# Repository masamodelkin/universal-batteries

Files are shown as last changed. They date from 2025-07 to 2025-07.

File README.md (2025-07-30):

# universal-batteries

Are you tired that all of those "wireless" devices actually require wires to charge them? Are you tired of all those wires on your table? Do you want to build a DIY project but you don't know what batteries to use? Or maybe you are not sure if wireless is the solution due to inconveniences with charging? 

If you answered yes to any of that, this project is for you! I personally answered yes to all of them, so I decided to make this modular battery system, so they can be swapped in seconds and no wires will be needed to charge any of the wireless tech that I have (not all of them, but most of them). 

This project introduces a simple design of a battery shell, charger and module that can be inserted into any project (or even existing electronics) to make it support hot-swap batteries and make all project batteries compatible with each other. 

The design features a charging station to charge 3 batteries at a time controlled with an ESP32-C6 allowing wireless control over it, battery shell design supporting 503759 batteries (1200mAh), and a battery bay to integrate into any project. 

This project is a work in progress, none of the electronics have been tested yet, including firmware and PCB. 

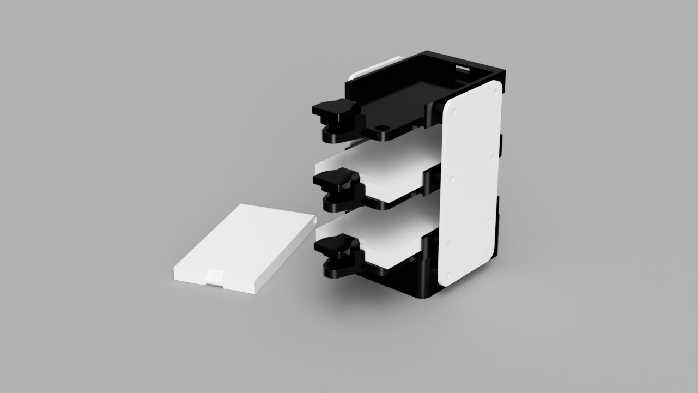
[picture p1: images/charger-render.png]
Charger render


Here is the routed PCB for the charger:

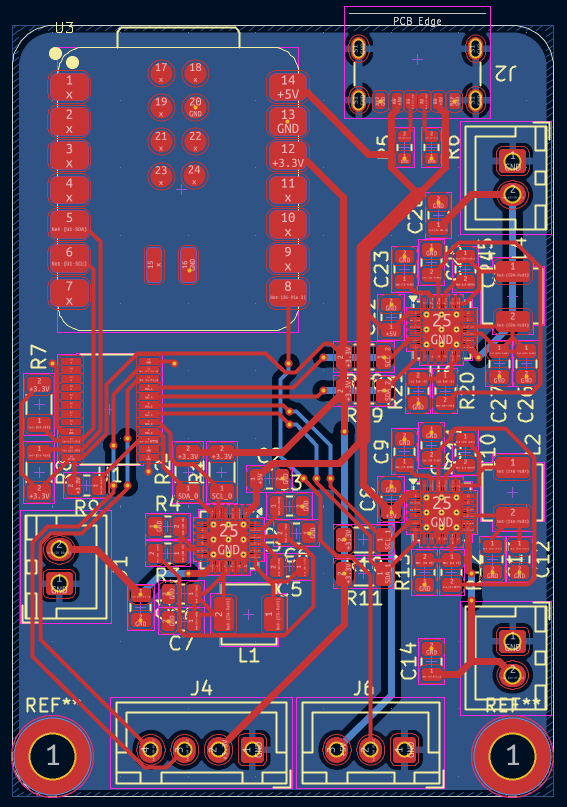
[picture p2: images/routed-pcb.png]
Complete routed PCB layout


## Bill of Materials (BOM)

| Component | Quantity | Unit Price | Total Price | Link |
|---|---|---|---|---|
| PCB (assembled) | 1 | 55.38 USD (35.38 + 20 shipping) | 55.38 USD | - |
| XIAO ESP32-C6 | 1 | 15.63 CAD (8.19 + 7.01 shipping + 0.43 antenna) | 15.63 CAD | [AliExpress](https://www.aliexpress.com/item/1005006935181127.html) |
| JST XH Connector Set (2-pin x3, 3-pin x1, 4-pin x1) | 1 | 6.92 CAD | 6.92 CAD | [AliExpress](https://www.aliexpress.com/item/1005009383841966.html) |
| Battery 503759 (1200mAh) | 3 | 14.94 CAD (pack of 3) | 14.94 CAD | [AliExpress](https://www.aliexpress.com/item/1005007102975858.html) |
| M3x6 Screws | 18 | - | - | - |
| M3x4x5 Heat Inserts | 18 | 7.55 CAD | 7.55 CAD | [AliExpress](https://www.aliexpress.com/item/1005009193787820.html) |
| Pogo Pins Connector 1x4 Male 4mm | 6 | 3.32 CAD | 19.92 CAD | [AliExpress](https://www.aliexpress.com/item/1005005380466642.html) |
| Pogo Pins Connector 1x4 Female 4mm | 6 | 3.48 CAD | 20.88 CAD | [AliExpress](https://www.aliexpress.com/item/1005005380466642.html) |
| Magnets 6x3mm | 18 | 11.24 CAD (4.33 + 6.91 shipping) | 11.24 CAD | [AliExpress](https://www.aliexpress.com/item/1005009258751295.html) |
| Magnets 6x2mm | 4 | 12.09 CAD (2.89 + 9.20 shipping) | 12.09 CAD | [AliExpress](https://www.aliexpress.com/item/1005009461555694.html) |
| PLA Filament | ~150g | Already own | 0.00 | - |
| **TOTAL** | | | **134.42 USD** | |

*Note: Prices include shipping where applicable. Some components may be sold in larger quantities than needed.*

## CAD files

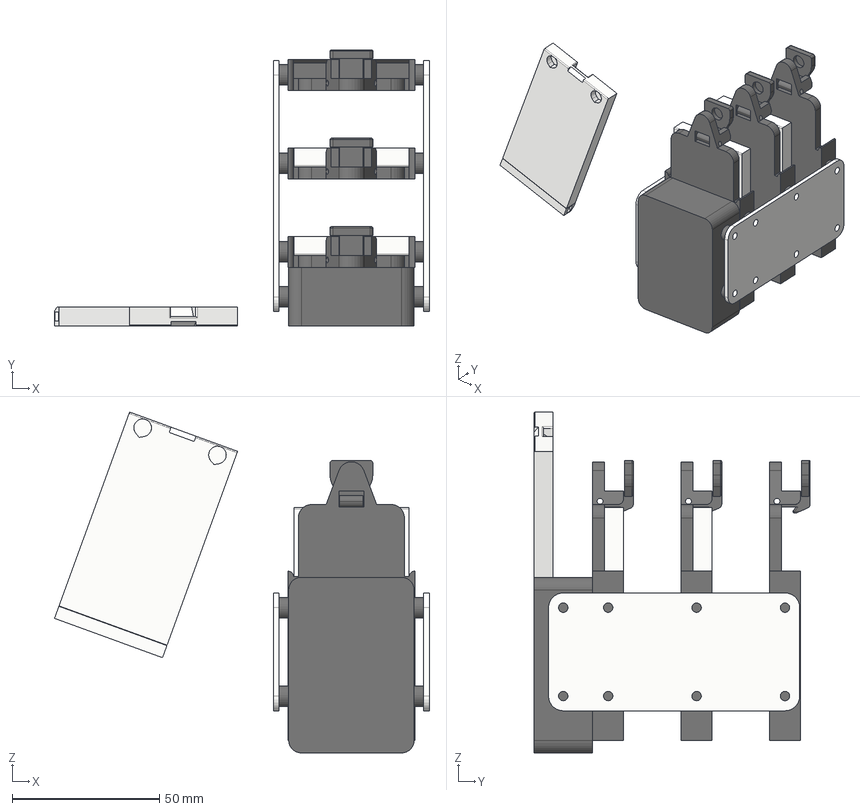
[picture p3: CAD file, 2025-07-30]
CAD/Removable batteries system.step
127.2 x 93.8 x 115.7 mm
Charger module x 3
Battery shell x 3
Battery cap x 3
Side panel x 2
JST_XH_B2B-XH-A_1x02_P2.50mm_Vertical x 3
C_0805_2012Metric x 21
R_1206_3216Metric x 8
R_0805_2012Metric x 7
TSSOP-24_4.4x7.8mm_P0.65mm
JST_XH_B4B-XH-A_1x04_P2.50mm_Vertical
Texas_RTW_WQFN-24-1EP_4x4mm_P0.5mm_EP2.7x2.7mm x 3
R_0603_1608Metric x 2
USB_C_Receptacle_GCT_USB4125-xx-x_6P_TopMnt_Horizontal
JST_XH_B3B-XH-A_1x03_P2.50mm_Vertical
1s_Battery_charger_PCB

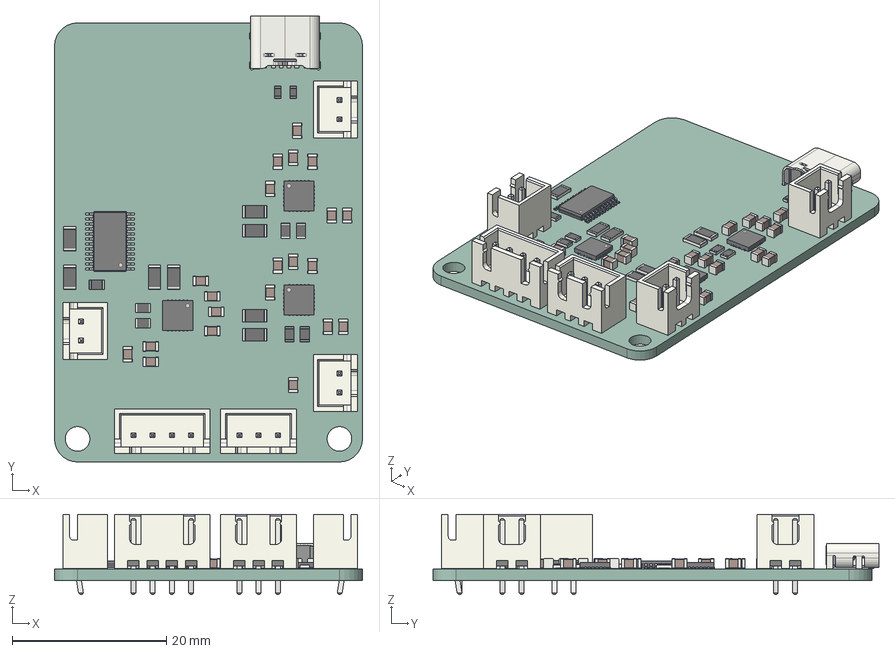
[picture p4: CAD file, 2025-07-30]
PCB/1s_Battery_charger.step
40.0 x 57.9 x 10.4 mm
JST_XH_B2B-XH-A_1x02_P2.50mm_Vertical x 3
C_0805_2012Metric x 21
R_1206_3216Metric x 8
R_0805_2012Metric x 7
TSSOP-24_4.4x7.8mm_P0.65mm
JST_XH_B4B-XH-A_1x04_P2.50mm_Vertical
Texas_RTW_WQFN-24-1EP_4x4mm_P0.5mm_EP2.7x2.7mm x 3
R_0603_1608Metric x 2
USB_C_Receptacle_GCT_USB4125-xx-x_6P_TopMnt_Horizontal
JST_XH_B3B-XH-A_1x03_P2.50mm_Vertical
1s_Battery_charger_PCB

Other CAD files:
CAD/Removable batteries system.f3z

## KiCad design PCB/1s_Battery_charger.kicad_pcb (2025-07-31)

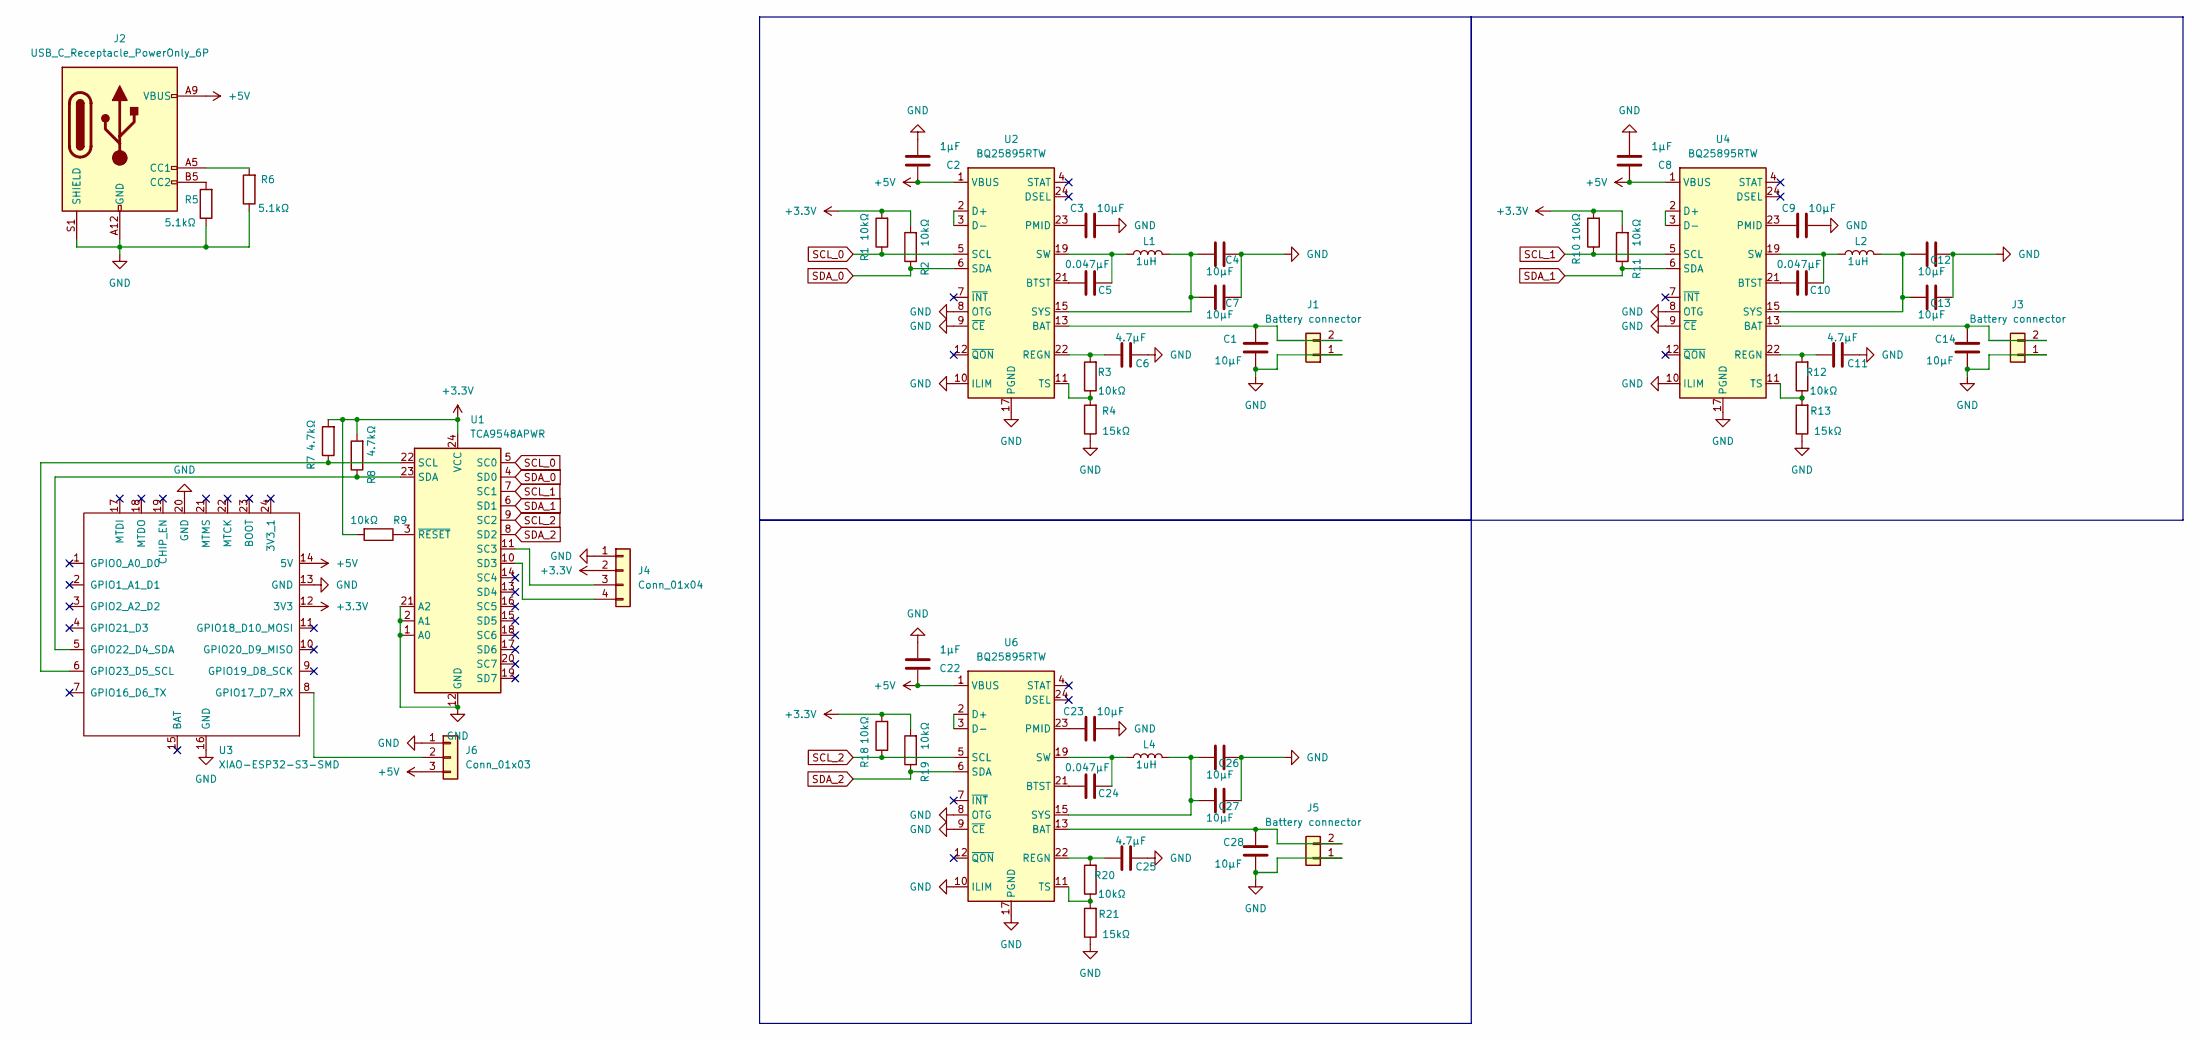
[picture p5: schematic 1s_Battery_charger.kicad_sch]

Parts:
C1, C14, C28: 10µF; C_0805_2012Metric
C2, C8, C22: 1μF; C_0805_2012Metric
C3, C4, C7, C9, C12, C13, C23, C26, C27: 10μF; C_0805_2012Metric
C5, C10, C24: 0.047μF; C_0805_2012Metric
C6, C11, C25: 4.7μF; C_0805_2012Metric
J1, J3, J5: Battery connector; JST_XH_B2B-XH-A_1x02_P2.50mm_Vertical
J2: USB_C_Receptacle_PowerOnly_6P; USB_C_Receptacle_GCT_USB4125-xx-x_6P_TopMnt_Horizontal
J4: Conn_01x04; JST_XH_B4B-XH-A_1x04_P2.50mm_Vertical
J6: Conn_01x03; JST_XH_B3B-XH-A_1x03_P2.50mm_Vertical
L1, L2, L4: 1uH; L_Changjiang_FXL0420
R1, R2, R10, R11, R18, R19: 10kΩ; R_1206_3216Metric
R3, R9, R12, R20: 10kΩ; R_0805_2012Metric
R4, R13, R21: 15kΩ; R_0805_2012Metric
R5, R6: 5.1kΩ; R_0603_1608Metric
R7, R8: 4.7kΩ; R_1206_3216Metric
U1: TCA9548APWR; TSSOP-24_4.4x7.8mm_P0.65mm
U2, U4, U6: BQ25895RTW; Texas_RTW_WQFN-24-1EP_4x4mm_P0.5mm_EP2.7x2.7mm_ThermalVias
U3: XIAO-ESP32-S3-SMD; XIAO-ESP32C6-SMD

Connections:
+3.3V: J4.2, R1.2, R2.2, R7.2, R8.2, R9.2, R10.2, R11.2, R18.2, R19.2, U1.24 (VCC), U3.12 (3V3)
+5V: C2.1, C8.1, C22.1, J2.A9 (VBUS), J2.B9 (VBUS), J6.3, U2.1 (VBUS), U3.14 (5V), U4.1 (VBUS), U6.1 (VBUS)
GND: C1.2, C2.2, C3.2, C4.2, C6.1, C7.2, C8.2, C9.2, C11.1, C12.2, C13.2, C14.2, C22.2, C23.2, C25.1, C26.2, C27.2, C28.2, J1.1, J2.A12 (GND), J2.B12 (GND), J2.S1 (SHIELD), J3.1, J4.1, J5.1, J6.1, R4.1, R5.1, R6.1, R13.1, R21.1, U1.1 (A0), U1.2 (A1), U1.12 (GND), U1.21 (A2), U2.8 (OTG), U2.9 (~CE), U2.10 (ILIM), U2.17 (PGND), U2.18 (PGND), U2.25 (PGND), U3.13 (GND), U3.16 (GND), U3.20 (GND), U4.8 (OTG), U4.9 (~CE), U4.10 (ILIM), U4.17 (PGND), U4.18 (PGND), U4.25 (PGND), U6.8 (OTG), U6.9 (~CE), U6.10 (ILIM), U6.17 (PGND), U6.18 (PGND), U6.25 (PGND)
unnamed: C4.1, C7.1, L1.2, U2.15 (SYS), U2.16 (SYS)
unnamed: C5.1, L1.1, U2.19 (SW), U2.20 (SW)
unnamed: C10.1, L2.1, U4.19 (SW), U4.20 (SW)
unnamed: C12.1, C13.1, L2.2, U4.15 (SYS), U4.16 (SYS)
unnamed: C24.1, L4.1, U6.19 (SW), U6.20 (SW)
unnamed: C26.1, C27.1, L4.2, U6.15 (SYS), U6.16 (SYS)
unnamed: C1.1, J1.2, U2.13 (BAT), U2.14 (BAT)
unnamed: J2.A5 (CC1), R6.2
unnamed: J2.B5 (CC2), R5.2
unnamed: C14.1, J3.2, U4.13 (BAT), U4.14 (BAT)
unnamed: J4.3, U1.11 (SC3)
unnamed: J4.4, U1.10 (SD3)
unnamed: C28.1, J5.2, U6.13 (BAT), U6.14 (BAT)
unnamed: J6.2, U3.8 (GPIO17_D7_RX)
unnamed: R7.1, U1.22 (SCL), U3.6 (GPIO23_D5_SCL)
unnamed: R8.1, U1.23 (SDA), U3.5 (GPIO22_D4_SDA)
unnamed: R9.1, U1.3 (~RESET)
unnamed: C5.2, U2.21 (BTST)
unnamed: U2.2 (D+), U2.3 (D-)
unnamed: C3.1, U2.23 (PMID)
unnamed: C6.2, R3.2, U2.22 (REGN)
unnamed: R3.1, R4.2, U2.11 (TS)
unnamed: C10.2, U4.21 (BTST)
unnamed: U4.2 (D+), U4.3 (D-)
unnamed: C9.1, U4.23 (PMID)
unnamed: C11.2, R12.2, U4.22 (REGN)
unnamed: R12.1, R13.2, U4.11 (TS)
unnamed: C24.2, U6.21 (BTST)
unnamed: U6.2 (D+), U6.3 (D-)
unnamed: C23.1, U6.23 (PMID)
unnamed: C25.2, R20.2, U6.22 (REGN)
unnamed: R20.1, R21.2, U6.11 (TS)
SCL_0: R1.1, U1.5 (SC0), U2.5 (SCL)
SCL_1: R10.1, U1.7 (SC1), U4.5 (SCL)
SCL_2: R18.1, U1.9 (SC2), U6.5 (SCL)
SDA_0: R2.1, U1.4 (SD0), U2.6 (SDA)
SDA_1: R11.1, U1.6 (SD1), U4.6 (SDA)
SDA_2: R19.1, U1.8 (SD2), U6.6 (SDA)

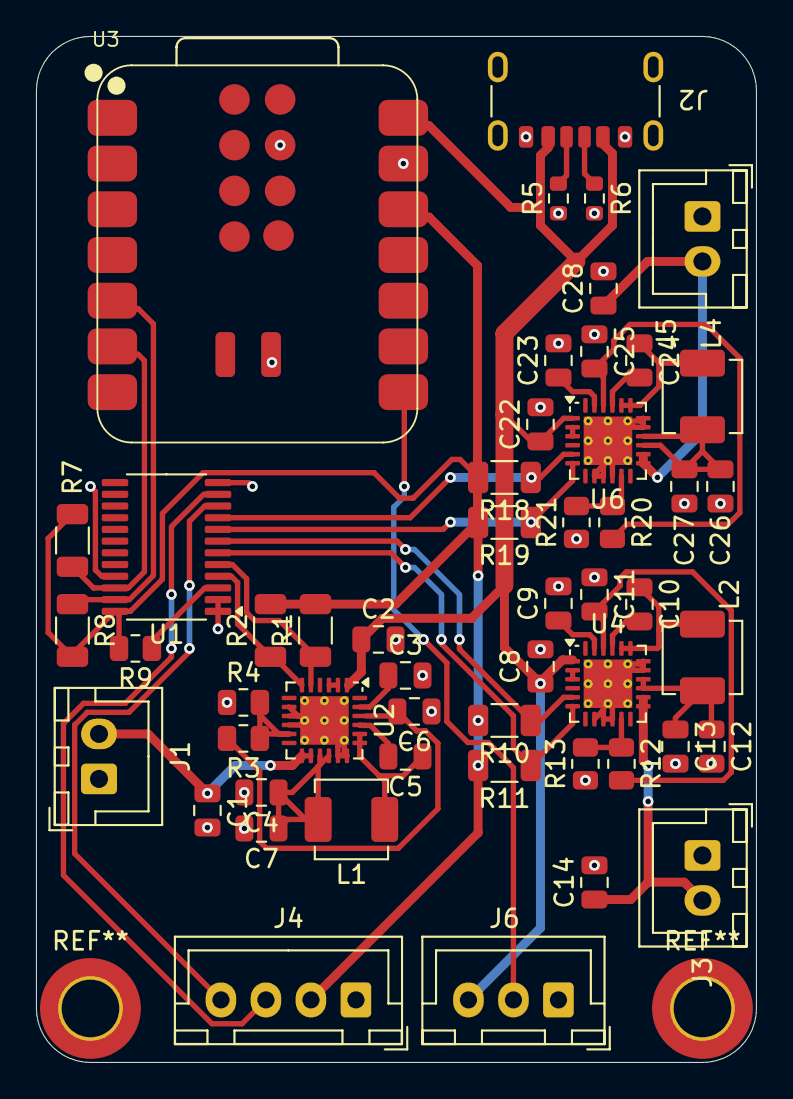
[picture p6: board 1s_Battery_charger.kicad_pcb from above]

Board: 2 copper layers, 40.0 x 57.0 mm, 52 parts (0 on the bottom side), 41 nets.

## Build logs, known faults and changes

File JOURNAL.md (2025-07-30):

---
title: "Universal batteries"
author: "Matthew Kutakh"
description: "System of quick-swap li-po batteries with a charger to eliminate recharging of the wireless devices"
created_at: "2025-06-01"
---
# Total time spent: 20h

# July 1st: Got quick release mechanism to work.

As my CAD of choice I used Fusion 360. 

There, I first designed and 3D printed a simple battery model to make sure that the rest of the build will be compatible with it since I do not have batteries yet. 
Then, I started working on a battery shell to house the battery in. By trial and error, I figured out that the best settings that worked were 0.5mm outer walls with one perimeter on a 0.4mm nozzle printed in the following orientation:

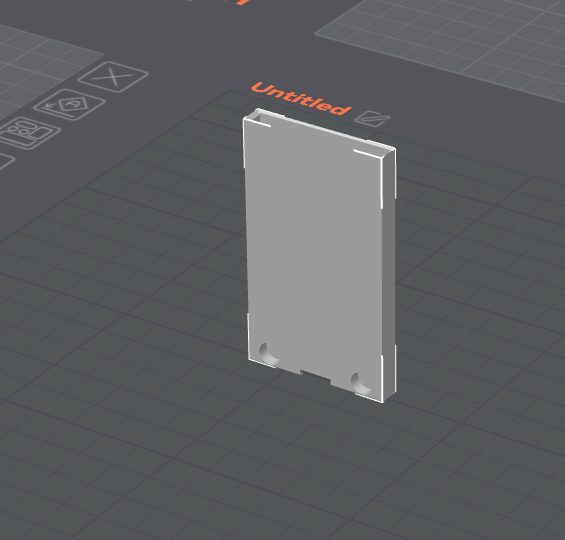
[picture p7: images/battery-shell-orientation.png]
Orientation of the battery shell in the slicer


Magnet holes at the bottom of the shell had to be made with an upside-down V shape at the top due to the printer's limited ability to bridge and holes orientation. The first iteration shell did not have those, resulting in the shell cracking when magnets were put in it. For the rest of the shells, the upside-down V shape was added and the issue was resolved. Below are pictures of the shell before and after the fix. 

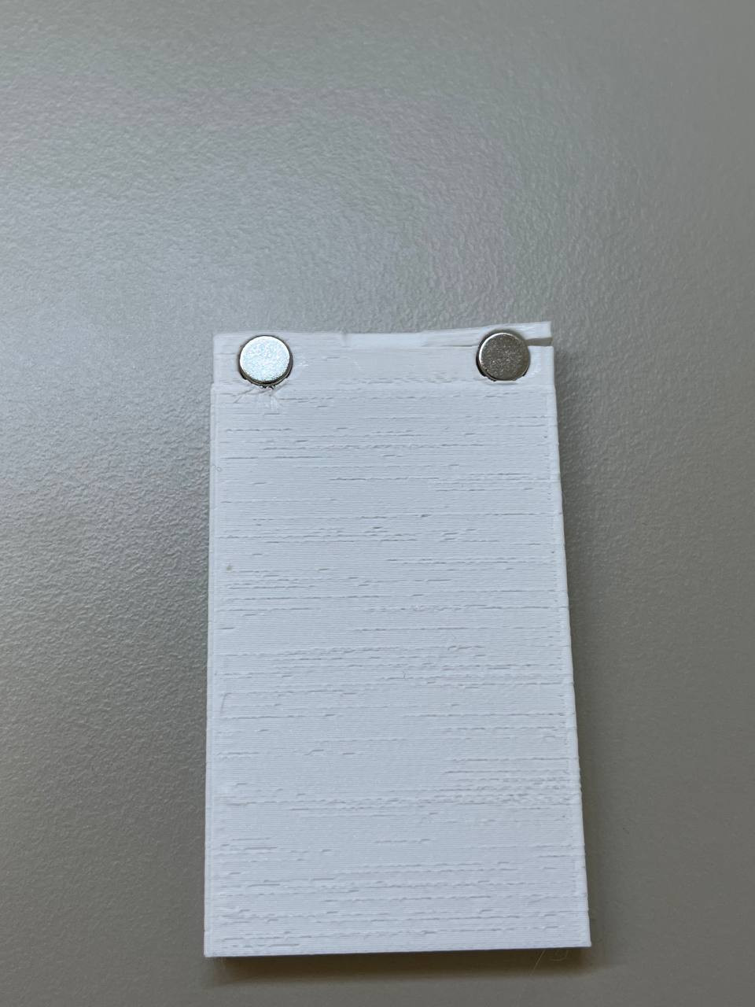
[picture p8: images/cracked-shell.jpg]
Cracked shell

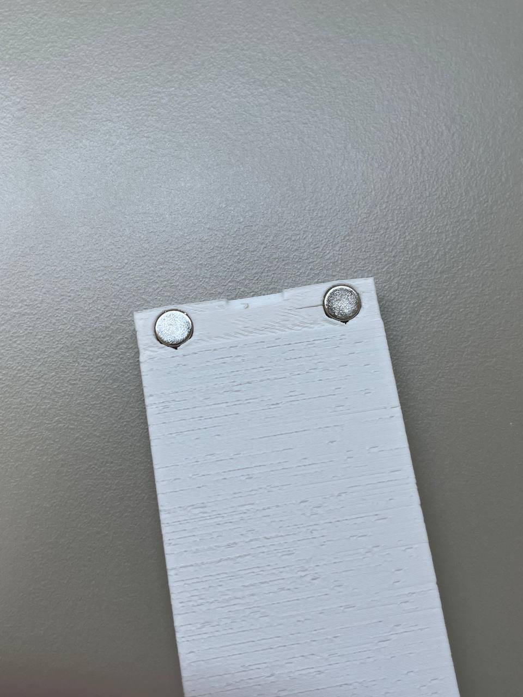
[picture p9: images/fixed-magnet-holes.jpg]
Shell with fixed magnets holes


Next, the mechanism was created.

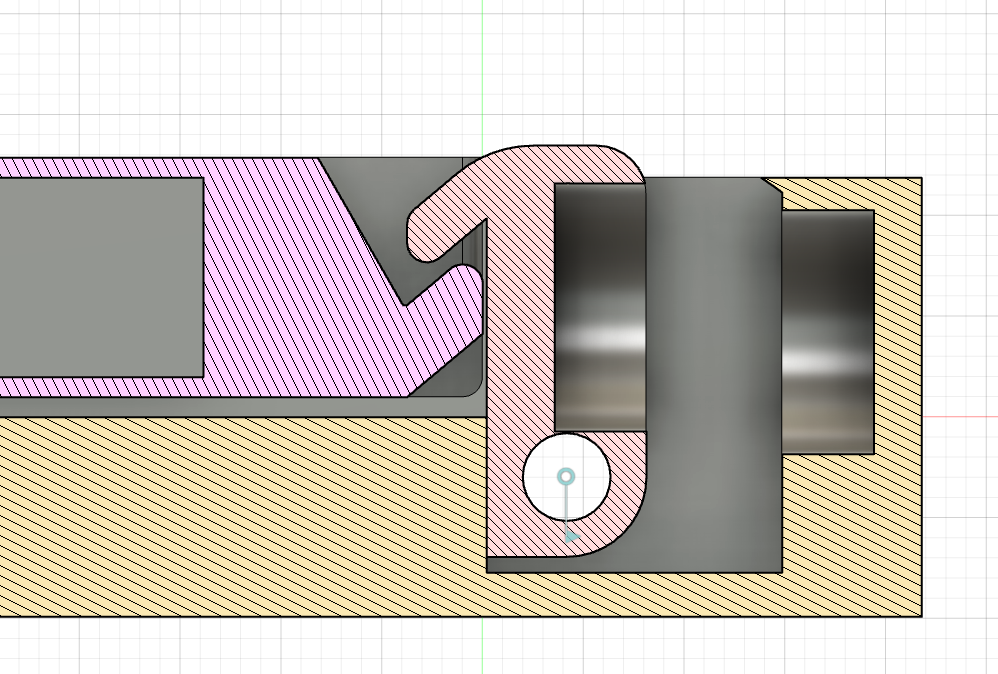
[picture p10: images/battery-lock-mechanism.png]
Mechanism of battery lock


The battery in the shell is repelled from the base up, where the locking mechanism does not let it go. Repulsion of the battery helps to hold it in position more securely and makes sure that even with time, the battery will stay in place and will not move no matter the tolerances. The lock uses another pair of magnets to make sure it is always in place and ensure a consistent battery insertion experience. This mechanism also uses a short piece of filament since it perfectly fits the small size of the mechanism. 

About 10 revisions of this lock were made before I was satisfied with the result. Its small size and imprecision of FDM 3D printing caused this challenge of getting reliable performance from this piece of mechanism. Below are most of the revisions of all parts that led to reliable and satisfying performance.

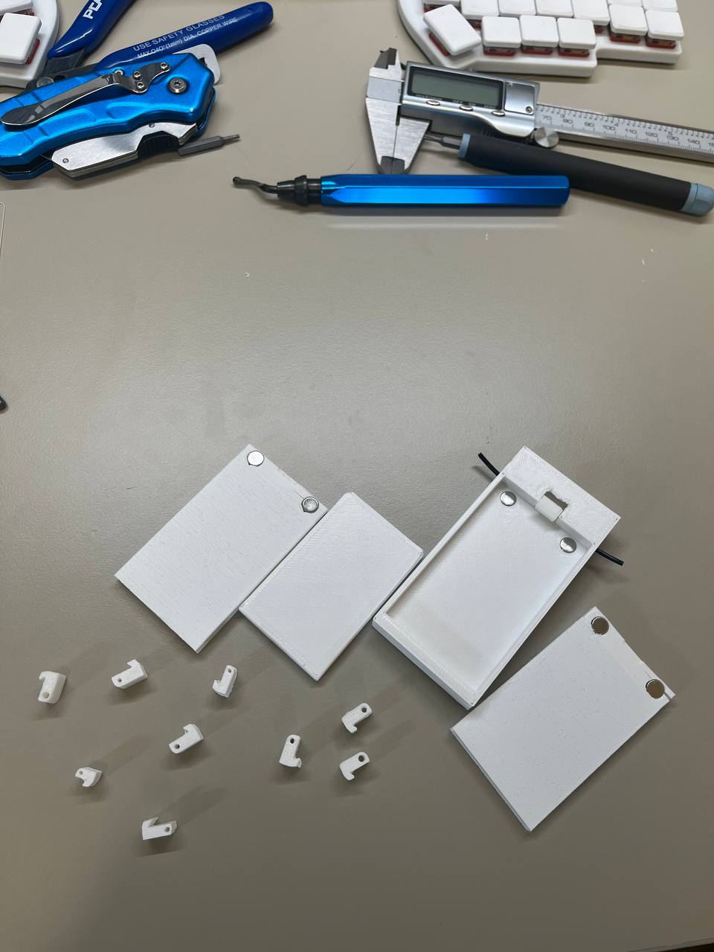
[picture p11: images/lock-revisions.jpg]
Multiple revisions of the lock mechanism


**Total time spent: 4h**

# July 3rd: Sorted out all the components needed

While charging a LiPo battery might seem like a trivial task at first, I had multiple requirements that made the choice of components way harder. Firstly, I want it to be a CC-CV charger, meaning that it starts charging with a constant current, slowly increasing the voltage and stays at 4.2V once it reaches it. This immediately rules out a simple solution of using simple circuitry to just give a steady 4.2 volts to the battery. Since these batteries have overcharge and overdischarge protection, this would probably work, but CC-CV can increase the longevity of the batteries. Another factor for me was the ability to monitor the battery state and the ability to stop the charging process from a microcontroller. 

At first I decided to use 2 ICs per battery: one for charging and one for monitoring. One of the candidates that I considered was a pair of MCP73831 as a charging IC and MAX17055 as a monitoring IC. This seemed like a great choice since it allows for getting a lot of information out of a battery, most importantly accurate battery percentage and battery health. 

However, after hours of consideration and reading datasheets and parts lists, I decided to pivot towards a different approach due to cost and PCB complexity considerations. I decided to use one IC for both charging and monitoring. After a bit more time spent looking at different options, I settled on using the BQ25895. It seems ideal since it does not require many additional components, making the PCB simpler, while still providing basic information about the battery such as voltage and current. However it has its own drawbacks such as limited information compared to the dedicated battery monitoring IC, but for the purpose of this project this is enough. 

Another challenge is that the charging IC is controlled via I2C protocol and its address cannot be changed, meaning that if I want to charge multiple batteries at the same time using the same controller, I need an I2C splitter and for that I used the TCA9548A - an 8 channel I2C splitter. 

For the microcontroller, I decided to use Seed Studio XIAO ESP32-C6 for its support of Zigbee, allowing me to connect it to my Home Assistant smart home with less dependence on wifi if I decide that I need this functionality. It also has a fairly small footprint allowing it to fit into the charger easily.

Overall, to find all those components, it took me a lot of time asking AI (Claude) for initial assistance to get to a starting point, searching through catalogs, reading documentation to finally settle on what I think are perfect components for my particular task. 

**Total time spent: 5h**

# July 6th: PCB making

Using the components mentioned above and appropriate datasheets, I started designing schematics for the PCB. I used [this](https://e2e.ti.com/cfs-file/__key/communityserver-discussions-components-files/196/BQ25895_5F00_SchematicChecklist-V1p1.pdf) schematics checklist I found online to ensure I used the right components for the BQ25895. 

After a couple hours, I had these schematics ready:

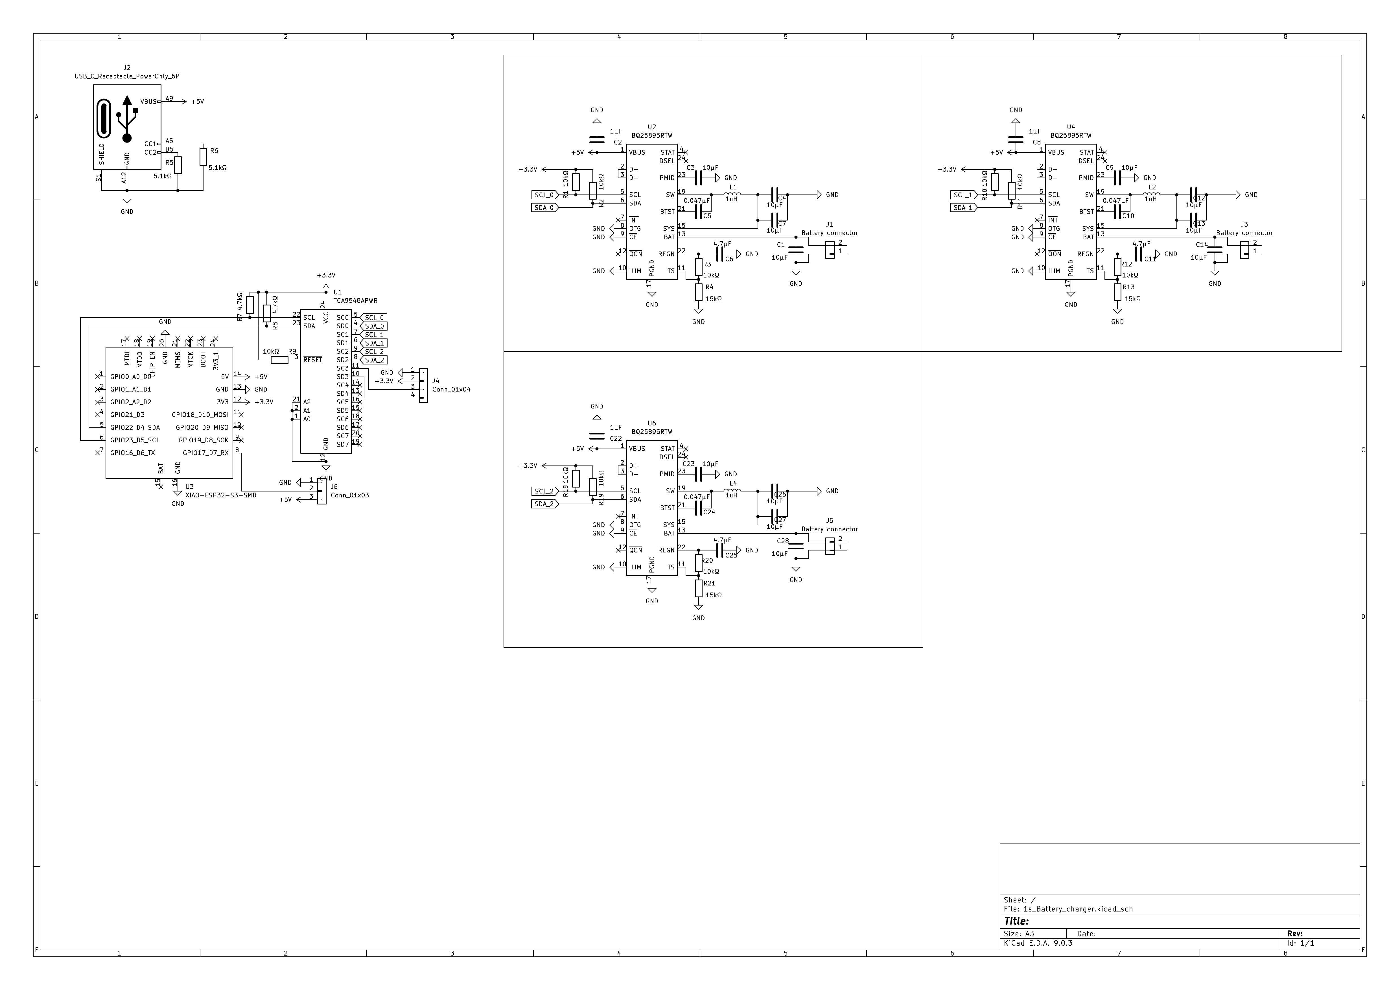
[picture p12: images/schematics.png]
PCB schematics for the universal battery charger


After that, I started designing the PCB. I decided to make a 2-layer PCB with one layer being a ground layer and the second one being a power and data layer. Although at the end, I had to make a couple of data and power traces going through the ground plane. 
I tried to make the PCB as compact as possible, more specifically make it smaller than the battery itself. 
After another couple hours, I had the PCB ready. Since I had a bit of space left on the board, I decided to include a connector for an I2C display as well as an addressable LED connector, in case I want to use any of that in the future. Here is the complete routed PCB:

Complete routed PCB layout

For assembly, I decided to use JLCPCB assembly for most of the components, soldering only JST connectors and the ESP32 by myself, since JLCPCB does not have that board and I already have connectors, and I also don't have to pay an additional hand assembly fee in this case. 

The same day, I wrote some code for the charger, but since I do not have any of the hardware, it probably does not work, I will make sure it is working after I get PCB. 

Also, shared schematics and PCB layout on Reddit, got some advice from other people and improved it a bit.

**Total time spent: 5h**

# July 28: Back to CAD

After taking a break with this project, I came back to Fusion to design the charger module. I considered a couple of different designs. Initially I wanted to mount batteries on the charger vertically, but after designing some vertical locking mechanisms, I realized that with the precision of FDM 3D printer and the lack of space on the battery shell, it is nearly impossible to make a reliable and consistent locking mechanism. Here are some designs that I tried:

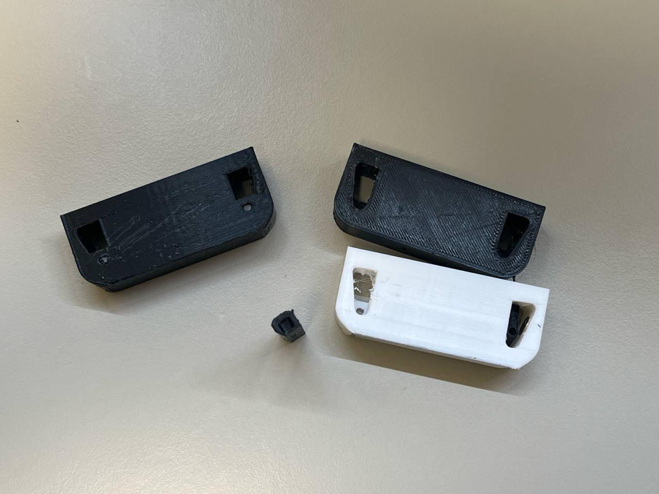
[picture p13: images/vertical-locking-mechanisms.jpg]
Locking mechanisms for vertical battery charging


After that, I decided to do a similar design to the battery holder. This turned out much better than all the previous designs, so I decided to make it bigger by laying batteries flat, but ensure the reliability of the mechanism. After a series of prototypes, I ended up with something that worked well for me.

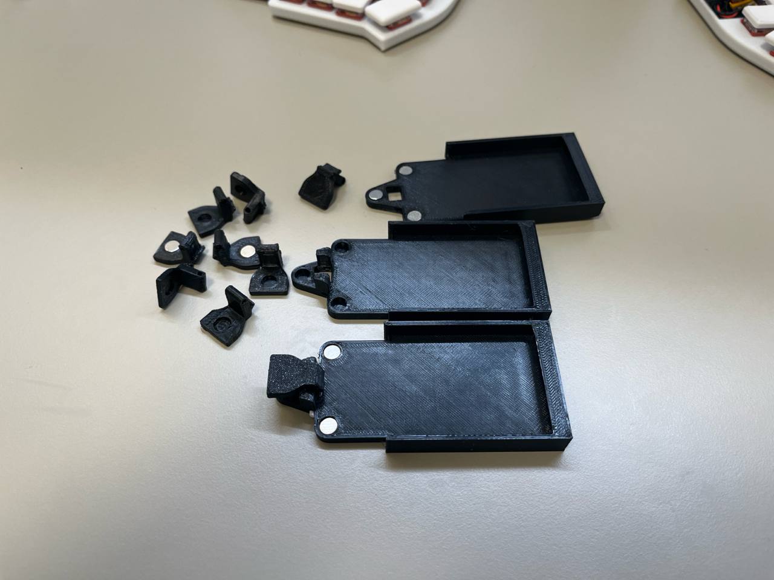
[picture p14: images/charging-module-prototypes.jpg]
Prototypes of a charging module


While all those small tabs might look the same, they are actually all different with some dimensions slightly changed. When I was happy with the charger module, I designed an enclosure for the charging PCB and side panels to connect all the modules together. 

Finally - Fusion 360 added constraints for components!!! The timing was just right (I wish they had done that earlier, but better late than never). With that, I was able to finish assembling the charger, which ended up looking like this:

Charger render

**Total time spent: 4h**

# July 30: Last day

Finally, with all the components ready, I started writing the README.md file and looking over all the journals and putting all the files into the GitHub repo. I also used Grammarly to correct grammatical mistakes in my Journal. 

**Total time spent: 2h**

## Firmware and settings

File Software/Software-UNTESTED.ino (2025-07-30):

#include <WiFi.h>
#include <ESPAsyncWebServer.h>
#include <ArduinoJson.h>
#include <Wire.h>
#include <SPIFFS.h>

// ============================================================================
// CONFIGURATION AND CONSTANTS
// ============================================================================

// WiFi Configuration
const char* WIFI_SSID = "your_wifi_ssid";
const char* WIFI_PASSWORD = "your_wifi_password";

// Hardware I2C Addresses
#define TCA9548_ADDRESS     0x70    // I2C multiplexer
#define BQ25895_ADDRESS     0x6A    // Battery charging IC (same on all channels)

// I2C Pin Configuration for ESP32-C6
#define I2C_SDA_PIN         6
#define I2C_SCL_PIN         7

// Charging System Configuration
#define NUM_CHARGERS        3
#define CHARGER_CHANNELS    {0, 1, 2}  // TCA9548 channels for each charger
#define TARGET_CHARGE_CURRENT_MA  500  // 0.5A charging current

// Web Server
AsyncWebServer server(80);

// ============================================================================
// DATA STRUCTURES
// ============================================================================

struct BatteryData {
    uint8_t channel;
    float voltage_v;          // Battery voltage in volts
    float charge_current_ma;  // Charging current in mA
    float bus_voltage_v;      // Input bus voltage
    uint8_t charge_status;    // Charging state (0=not charging, 1=pre-charge, 2=fast charge, 3=done)
    uint8_t fault_status;     // Fault register value
    bool is_charging;         // Simplified charging indicator
    bool has_fault;          // Simplified fault indicator
    uint32_t last_update;    // Timestamp of last update
    bool is_online;          // Device communication status
};

struct SystemStatus {
    uint32_t uptime_ms;
    uint8_t active_chargers;
    int8_t wifi_rssi;
    uint32_t free_heap;
    bool system_healthy;
};

// ============================================================================
// GLOBAL VARIABLES
// ============================================================================

BatteryData batteries[NUM_CHARGERS];
SystemStatus system_status;
uint8_t charger_channels[] = CHARGER_CHANNELS;
SemaphoreHandle_t i2c_mutex;

// ============================================================================
// BQ25895RTW REGISTER DEFINITIONS AND FUNCTIONS
// ============================================================================

// BQ25895RTW Register Addresses
#define BQ25895_REG_ILIM         0x00  // Input current limit
#define BQ25895_REG_VINDPM       0x01  // Input voltage limit
#define BQ25895_REG_ADC          0x02  // ADC control
#define BQ25895_REG_SYS          0x03  // System configuration
#define BQ25895_REG_ICHG         0x04  // Fast charge current
#define BQ25895_REG_IPRECHG      0x05  // Pre-charge/termination current
#define BQ25895_REG_VREG         0x06  // Charge voltage limit
#define BQ25895_REG_TIMER        0x07  // Charge timer control
#define BQ25895_REG_BAT_COMP     0x08  // Battery compensation
#define BQ25895_REG_BOOST        0x0A  // Boost configuration
#define BQ25895_REG_STATUS       0x0B  // System status
#define BQ25895_REG_FAULT        0x0C  // Fault status
#define BQ25895_REG_VINDPM_STAT  0x0D  // Input voltage status
#define BQ25895_REG_ADC_VBUS     0x0E  // ADC Bus voltage
#define BQ25895_REG_ADC_VPMID    0x0F  // ADC PMID voltage
#define BQ25895_REG_ADC_VBAT     0x10  // ADC Battery voltage
#define BQ25895_REG_ADC_VSYS     0x11  // ADC System voltage  
#define BQ25895_REG_ADC_ICHG     0x12  // ADC Charge current
#define BQ25895_REG_ADC_IDPM     0x13  // ADC Input current
#define BQ25895_REG_RESET        0x14  // Device reset

// Configuration values for 0.5A (512mA actual) charging current
struct BQ25895Config {
    uint8_t reg;
    uint8_t value;
    const char* description;
};

const BQ25895Config bq25895_init_sequence[] = {
    {BQ25895_REG_RESET,    0x80, "Software reset"},
    {BQ25895_REG_ILIM,     0x30, "Input current limit ~500mA, disable ILIM pin"},
    {BQ25895_REG_ADC,      0x9D, "Enable continuous ADC conversion, ICO"},
    {BQ25895_REG_SYS,      0x1A, "Enable charging, 3.5V min system voltage"},
    {BQ25895_REG_ICHG,     0x08, "Fast charge current = 512mA (8 × 64mA)"},
    {BQ25895_REG_IPRECHG,  0x83, "Pre-charge 192mA, termination 192mA"},
    {BQ25895_REG_VREG,     0x5E, "Charge voltage 4.208V for LiPo"},
    {BQ25895_REG_TIMER,    0x8D, "Disable watchdog, enable charging safety timer"}
};

// ============================================================================
// I2C MULTIPLEXER FUNCTIONS
// ============================================================================

bool tca9548_select_channel(uint8_t channel) {
    if (channel > 7) return false;
    
    if (xSemaphoreTake(i2c_mutex, pdMS_TO_TICKS(100)) != pdTRUE) {
        Serial.println("Failed to acquire I2C mutex");
        return false;
    }
    
    Wire.beginTransmission(TCA9548_ADDRESS);
    Wire.write(1 << channel);  // Enable only selected channel
    uint8_t error = Wire.endTransmission();
    
    if (error == 0) {
        delayMicroseconds(100);  // Channel settling time
        return true;
    } else {
        Serial.printf("TCA9548 channel %d selection failed: %d\n", channel, error);
        xSemaphoreGive(i2c_mutex);
        return false;
    }
}

void tca9548_release_channel() {
    // Deselect all channels
    Wire.beginTransmission(TCA9548_ADDRESS);
    Wire.write(0x00);
    Wire.endTransmission();
    
    xSemaphoreGive(i2c_mutex);
}

bool tca9548_scan_channels() {
    Serial.println("Scanning I2C channels...");
    bool found_devices = false;
    
    for (uint8_t channel = 0; channel < 8; channel++) {
        if (tca9548_select_channel(channel)) {
            Serial.printf("Channel %d: ", channel);
            bool found_on_channel = false;
            
            for (uint8_t addr = 1; addr < 127; addr++) {
                Wire.beginTransmission(addr);
                if (Wire.endTransmission() == 0) {
                    Serial.printf("0x%02X ", addr);
                    found_on_channel = true;
                    found_devices = true;
                }
            }
            
            if (!found_on_channel) {
                Serial.print("No devices");
            }
            Serial.println();
            
            tca9548_release_channel();
        }
    }
    
    return found_devices;
}

// ============================================================================
// BQ25895RTW COMMUNICATION FUNCTIONS
// ============================================================================

bool bq25895_write_register(uint8_t reg, uint8_t value) {
    Wire.beginTransmission(BQ25895_ADDRESS);
    Wire.write(reg);
    Wire.write(value);
    uint8_t error = Wire.endTransmission();
    
    if (error != 0) {
        Serial.printf("BQ25895 write reg 0x%02X failed: %d\n", reg, error);
        return false;
    }
    return true;
}

bool bq25895_read_register(uint8_t reg, uint8_t* value) {
    Wire.beginTransmission(BQ25895_ADDRESS);
    Wire.write(reg);
    uint8_t error = Wire.endTransmission(false);  // Repeated start
    
    if (error != 0) {
        Serial.printf("BQ25895 read setup reg 0x%02X failed: %d\n", reg, error);
        return false;
    }
    
    Wire.requestFrom(BQ25895_ADDRESS, (uint8_t)1);
    if (Wire.available()) {
        *value = Wire.read();
        return true;
    } else {
        Serial.printf("BQ25895 read reg 0x%02X no data\n", reg);
        return false;
    }
}

bool bq25895_initialize() {
    Serial.println("Initializing BQ25895RTW for 0.5A charging...");
    
    // Software reset first
    if (!bq25895_write_register(BQ25895_REG_RESET, 0x80)) {
        Serial.println("BQ25895 reset failed");
        return false;
    }
    delay(10);  // Wait for reset
    
    // Clear reset bit
    if (!bq25895_write_register(BQ25895_REG_RESET, 0x00)) {
        return false;
    }
    delay(10);
    
    // Apply configuration sequence
    const int config_count = sizeof(bq25895_init_sequence) / sizeof(bq25895_init_sequence[0]);
    
    for (int i = 1; i < config_count; i++) {  // Skip first entry (reset) 
        const BQ25895Config& config = bq25895_init_sequence[i];
        
        if (!bq25895_write_register(config.reg, config.value)) {
            Serial.printf("BQ25895 config failed at reg 0x%02X: %s\n", 
                         config.reg, config.description);
            return false;
        }
        delay(1);
    }
    
    Serial.println("BQ25895RTW initialization complete");
    return true;
}

bool bq25895_read_status(BatteryData* battery) {
    uint8_t status_reg, fault_reg, adc_vbat, adc_vbus, adc_ichg;
    
    // Read critical registers
    if (!bq25895_read_register(BQ25895_REG_STATUS, &status_reg) ||
        !bq25895_read_register(BQ25895_REG_FAULT, &fault_reg) ||
        !bq25895_read_register(BQ25895_REG_ADC_VBAT, &adc_vbat) ||
        !bq25895_read_register(BQ25895_REG_ADC_VBUS, &adc_vbus) ||
        !bq25895_read_register(BQ25895_REG_ADC_ICHG, &adc_ichg)) {
        return false;
    }
    
    // Parse status register (bits 4:3 = charging status)
    battery->charge_status = (status_reg >> 3) & 0x03;
    battery->is_charging = (battery->charge_status == 1 || battery->charge_status == 2);
    
    // Parse fault register
    battery->fault_status = fault_reg;
    battery->has_fault = (fault_reg != 0);
    
    // Convert ADC readings to real values
    battery->voltage_v = 2.304 + (adc_vbat & 0x7F) * 0.020;  // Battery voltage
    battery->bus_voltage_v = 2.600 + (adc_vbus & 0x7F) * 0.100;  // Bus voltage
    battery->charge_current_ma = (adc_ichg & 0x7F) * 50;  // Charge current
    
    battery->last_update = millis();
    battery->is_online = true;
    
    return true;
}

// ============================================================================
// CHARGING SYSTEM FUNCTIONS
// ============================================================================

void initialize_charging_system() {
    Serial.println("Initializing charging system...");
    
    // Initialize each charger
    system_status.active_chargers = 0;
    
    for (uint8_t i = 0; i < NUM_CHARGERS; i++) {
        uint8_t channel = charger_channels[i];
        
        Serial.printf("Initializing charger %d on channel %d...\n", i + 1, channel);
        
        if (tca9548_select_channel(channel)) {
            if (bq25895_initialize()) {
                batteries[i].channel = channel;
                batteries[i].is_online = true;
                system_status.active_chargers++;
                Serial.printf("Charger %d initialized successfully\n", i + 1);
            } else {
                batteries[i].is_online = false;
                Serial.printf("Charger %d initialization failed\n", i + 1);
            }
            tca9548_release_channel();
        } else {
            batteries[i].is_online = false;
            Serial.printf("Failed to select channel %d for charger %d\n", channel, i + 1);
        }
        
        delay(10);  // Brief pause between initializations
    }
    
    Serial.printf("Charging system initialized: %d/%d chargers active\n", 
                 system_status.active_chargers, NUM_CHARGERS);
}

void update_all_batteries() {
    static uint32_t last_update = 0;
    const uint32_t update_interval = 2000;  // 2 seconds
    
    if (millis() - last_update < update_interval) {
        return;
    }
    
    for (uint8_t i = 0; i < NUM_CHARGERS; i++) {
        if (!batteries[i].is_online) continue;
        
        uint8_t channel = charger_channels[i];
        
        if (tca9548_select_channel(channel)) {
            if (!bq25895_read_status(&batteries[i])) {
                batteries[i].is_online = false;
                Serial.printf("Lost communication with charger %d\n", i + 1);
            }
            tca9548_release_channel();
        }
        
        delay(1);  // Brief pause between readings
    }
    
    last_update = millis();
}

// ============================================================================
// SAFETY MONITORING
// ============================================================================

void check_safety() {
    bool system_fault = false;
    
    for (uint8_t i = 0; i < NUM_CHARGERS; i++) {
        if (!batteries[i].is_online) continue;
        
        BatteryData& battery = batteries[i];
        
        // Check critical safety limits
        if (battery.voltage_v > 4.25) {  // Overvoltage
            Serial.printf("CRITICAL: Battery %d overvoltage: %.2fV\n", i + 1, battery.voltage_v);
            system_fault = true;
        }
        
        if (battery.voltage_v < 2.5) {  // Severely undervoltage
            Serial.printf("CRITICAL: Battery %d undervoltage: %.2fV\n", i + 1, battery.voltage_v);
            system_fault = true;
        }
        
        if (battery.charge_current_ma > 1000) {  // Overcurrent
            Serial.printf("CRITICAL: Battery %d overcurrent: %.0fmA\n", i + 1, battery.charge_current_ma);
            system_fault = true;
        }
        
        if (battery.has_fault) {
            Serial.printf("WARNING: Battery %d fault register: 0x%02X\n", i + 1, battery.fault_status);
        }
    }
    
    system_status.system_healthy = !system_fault;
    
    if (system_fault) {
        // Could implement emergency shutdown here
        Serial.println("SYSTEM FAULT DETECTED - Monitor closely");
    }
}

// ============================================================================
// WEB SERVER FUNCTIONS
// ============================================================================

String get_charge_status_string(uint8_t status) {
    switch (status) {
        case 0: return "Not Charging";
        case 1: return "Pre-charge";
        case 2: return "Fast Charge";
        case 3: return "Charge Done";
        default: return "Unknown";
    }
}

float calculate_battery_percentage(float voltage) {
    // LiPo voltage to percentage approximation
    if (voltage >= 4.2) return 100.0;
    if (voltage <= 3.0) return 0.0;
    return ((voltage - 3.0) / 1.2) * 100.0;
}
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
void loop() {
    static uint32_t last_status_print = 0;
    static uint32_t last_safety_check = 0;
    
    // Update battery readings
    update_all_batteries();
    
    // Safety monitoring every 5 seconds
    if (millis() - last_safety_check > 5000) {
        check_safety();
        last_safety_check = millis();
    }
    
    // Print status summary every 10 seconds
    if (millis() - last_status_print > 10000) {
        Serial.println("\n--- Battery Status Summary ---");
        for (uint8_t i = 0; i < NUM_CHARGERS; i++) {
            if (batteries[i].is_online) {
                Serial.printf("Battery %d: %.2fV, %.0fmA, %s, Ch%d\n", 
                             i + 1, 
                             batteries[i].voltage_v,
                             batteries[i].charge_current_ma,
                             get_charge_status_string(batteries[i].charge_status).c_str(),
                             batteries[i].channel);
            } else {
                Serial.printf("Battery %d: OFFLINE\n", i + 1);
            }
        }
        Serial.printf("System: %s, WiFi: %d dBm, Heap: %d bytes\n", 
                     system_status.system_healthy ? "Healthy" : "Fault",
                     WiFi.RSSI(), 
                     ESP.getFreeHeap());
        Serial.println("-----------------------------\n");
        
        last_status_print = millis();
    }
    
    // Main loop delay
    delay(100);
}

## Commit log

2025-07-30 BOM added to README
2025-07-31 Fixed the issue with XIAO module being too far from the board edge
    [1s_Battery_charger.kicad_pcb]
